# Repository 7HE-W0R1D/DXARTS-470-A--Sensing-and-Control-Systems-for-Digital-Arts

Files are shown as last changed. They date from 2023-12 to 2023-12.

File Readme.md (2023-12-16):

# RetroConnect: Retrofit Telephone 
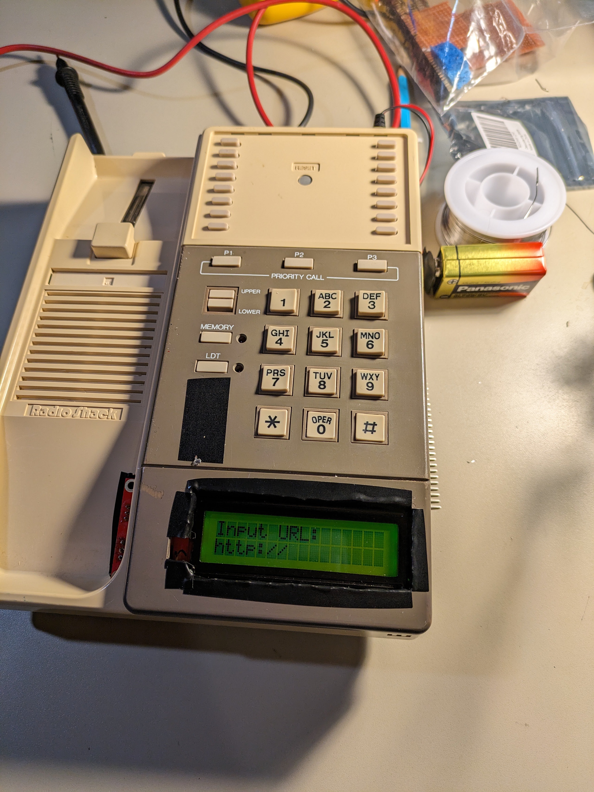
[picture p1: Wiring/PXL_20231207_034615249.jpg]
RetroConnect Phone


## Description
The Internet-Connected Retro Telephone is a project born out of a fascination with IoT and telecommunication. The motivation behind this endeavor is to explore the rapid evolution of technology and the stark differences in devices used over the past decades. By repurposing an old telephone, the project aims to showcase the transformative journey from traditional rotary dial phones to modern smart IoT devices. Additionally, it delves into the emergence of wireless technology, filling our surroundings with invisible data flows.

The project itself is a retrofit telephone equipped with up-to-date WiFi technology, serving as an interpreter of the invisible data flow around us. Users can connect to the internet using this device, experiencing the blend of old and new technologies. The telephone generates different characters and beeps at varying frequencies based on the delay of accessing websites. WiFi connectivity is provided through an ESP 8266 WiFi module connected to the Arduino, while character display is achieved using a 1602 Serial enabled LCD. Beeping and key input are facilitated through the telephone's original keypad and speaker.

## Table of Contents
- [Schematic](#schematic)
- [Installation](#installation)
- [Usage](#usage)

## Schematic
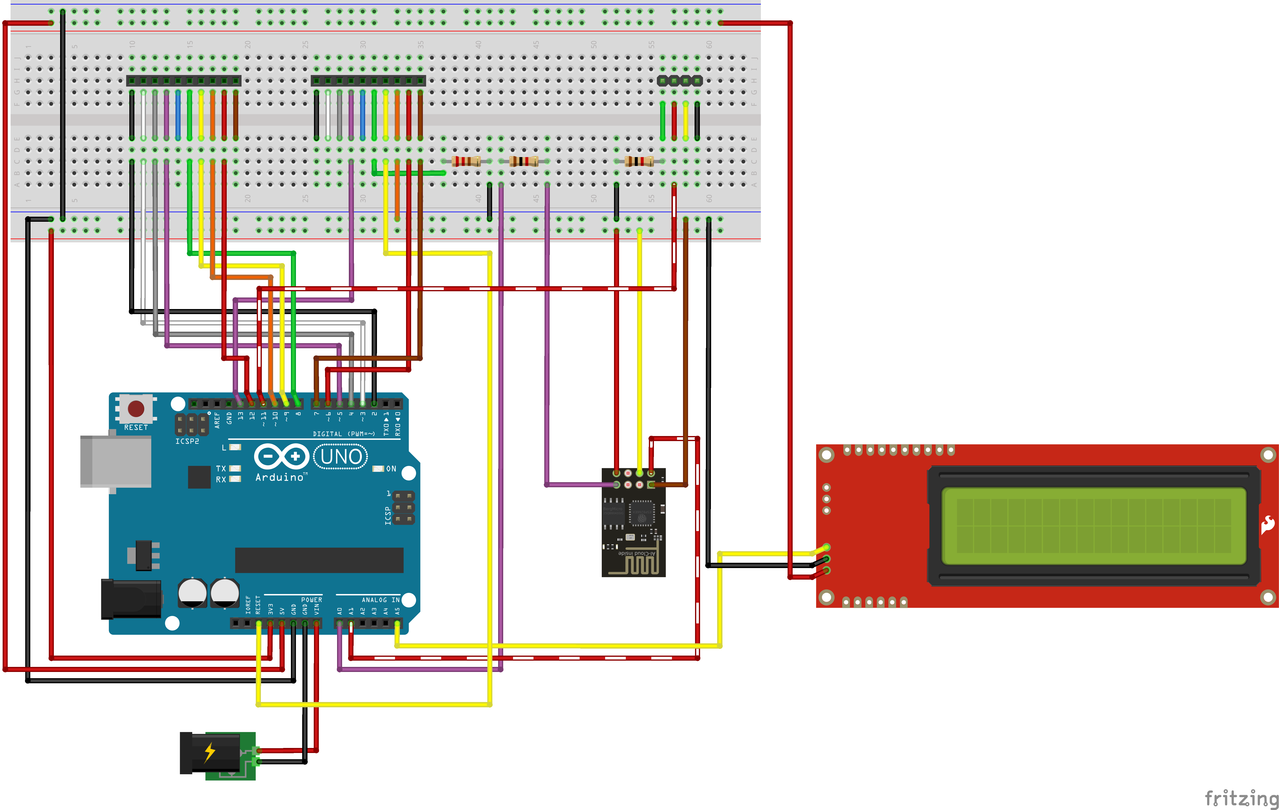
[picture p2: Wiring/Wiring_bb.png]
Wiring Breadboard View Wiring in Breadboard View

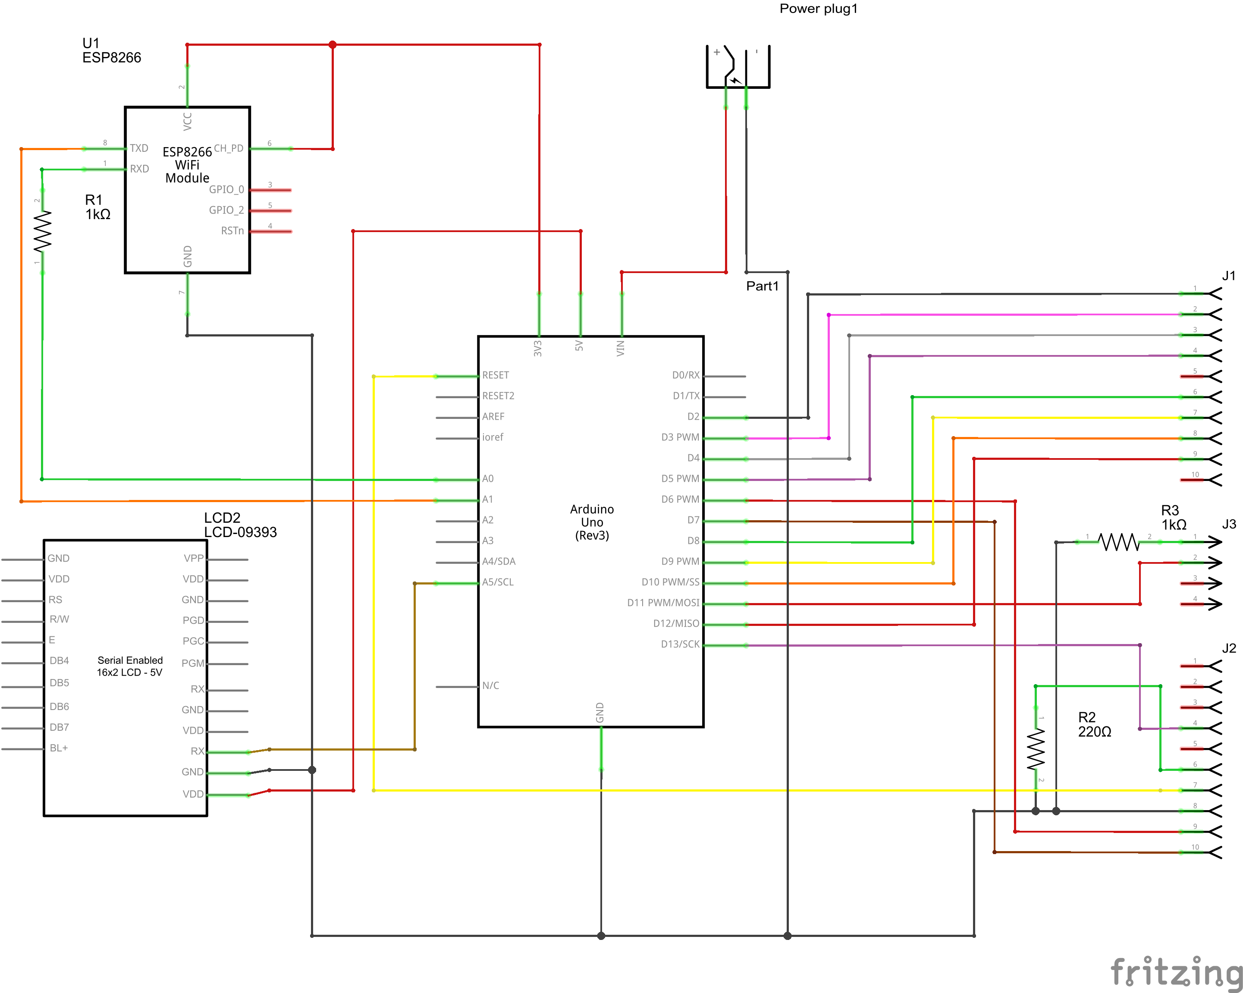
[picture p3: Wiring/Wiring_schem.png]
Wiring Schematic View Wiring in Shematic View

The two 10 pin connectors are the key connector from the telephone, the key mapping can be found in the __Phone Key test.xlsx__ file. Wires are in the same order in the breadboard graph and the actual connector, both from left to right. The 4 pin connector is the telephone's speaker & mic connector, also preserved the original color in the breadboard view. 
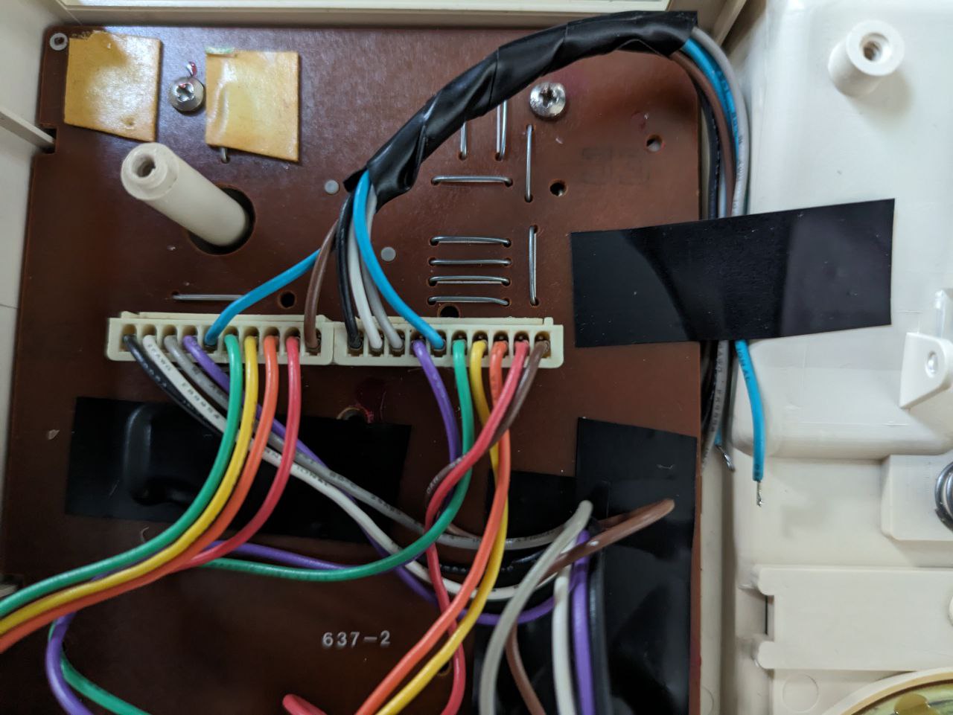
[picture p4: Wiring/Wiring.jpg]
Key Connector Key Connector Graph


## Installation Notes
Some important notes to make the phone work properly

- Connect the ESP 8266 WIFI module to the Arduino and run the ``ESP 8266 Setup.ino`` file once to set the default baud rate to 9600, 115200 is too fast for stable communication.
- When developing, do not send too many commands at once to the ESP 8266, add delays between commands
- The ``lcd.clear()`` function in the SerLCD library is not working properly so print spaces (" ") to clear the screen.
- Careful about the external reset button, especially when flipped the PCB board. Make sure the Arduino is not resetting infinitely.

## Usage
Once installed, RetroConnect can be used to connect to the internet and access websites. Users can input URLs using the original telephone keypad, and the device will respond with characters and beeps corresponding to the site's delay. This unique interaction aims to make users reflect on the evolution of technology while experiencing the charm of vintage communication devices.

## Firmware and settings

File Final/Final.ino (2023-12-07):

#include <SoftwareSerial.h>
#include <Keypad.h>
#include <Wire.h>
#include <SerLCD.h>

// LCD
SoftwareSerial lcdSerial(A4, A5); // RX, TX
SerLCD lcd;

// Wifi
SoftwareSerial espSerial(A1, A0); // RX, TX
String ssid_home = "BreakfastBerry";
String password_home = "N;9263k2";
String ssid_x13 = "ThinkPad";
String password_x13 = "AMD4750u";
String ssid = "UW MPSK";
// String password = ":$SpEL7<*7"; // Model 01 Old
String password = "EKAgE6=,Ur"; // Model 02 New

// Buzzer
int buzzerPin = 11; // set the buzzer pin
int frequency = 0; // initialize the frequency variable

static int Tones_simple[] ={31, 33, 37, 41, 44, 49, 55, 62, 65, 73, 82, 87, 98, 110, 123, 131, 147, 165,
 175, 196, 220, 247, 262, 294, 330, 349, 392, 440, 494, 523, 587, 659, 698, 784, 880, 988, 1047};

// Keypad
const byte ROWS = 4;
const byte COLS = 5;

// Wiring: 2 3 4 5 8 9 10 12 || 13

// < is P1, > is P2, ~ is P3
char keys[ROWS][COLS] = {
//          8    5    4    3    2
/* 9  */  {'~', '1', '2', '3', ' '},
/* 10 */  {'>', '4', '5', '6', '-'},
/* 13 */  {'<', '7', '8', '9', '_'},
/* 12 */  {'(', '*', '0', '#', '/'}
};

String multiEnabled = "0123456789";
String keyStringArray_Capital[10] = {
  "0Z.",
  "1", "2ABC", "3DEF",
  "4GHI", "5JKL", "6MNO",
  "7PQRS", "8TUV", "9WXY"
};

String keyStringArray[10] = {
  "0z.",
  "1", "2abc", "3def",
  "4ghi", "5jkl", "6mno",
  "7pqrs", "8tuv", "9wxy"
};

byte rowPins[ROWS] = {9, 10, 13, 12};
byte colPins[COLS] = {8, 5, 4, 3, 2};

Keypad keypad = Keypad(makeKeymap(keys), rowPins, colPins, ROWS, COLS);
int multiPressDelay = 1000;
String result = "";

// ASCII
String ASCIIStr = "";
char intToASCII(int , boolean = true);

String serialPrompt(String = "Please enter your PING target: ");

// LED
int ledUPin = 6; // Upper LED, PWM
int ledDPin = 7; // Lower LED, no PWM

void setup()
{
  pinMode(buzzerPin, OUTPUT); // set the buzzer pin as an output
  pinMode(ledUPin, OUTPUT);
  pinMode(ledDPin, OUTPUT);
  Serial.begin(9600);

  lcdSerial.begin(9600);
  // Initialize the LCD
  lcd.begin(lcdSerial);
  // Clear the LCD screen
  lcdClear();
  delay(500);

  espSerial.begin(9600);
  espSerial.listen();
  delay(500);
  digitalWrite(ledUPin, HIGH);
  delay(100);
  digitalWrite(ledDPin, HIGH);
  delay(500);
  digitalWrite(ledUPin, LOW);
  delay(100);
  digitalWrite(ledDPin, LOW);

  // Serial.println("Setting ESP8266 to station mode...");
  lcd.print("Setting ESP8266");
  lcd.setCursor(0, 1);
  lcd.print("to station mode...");
  espSerial.println("AT+CWMODE=1");
  delay(1000);

  lcdClear();
  // Serial.println("Connecting to WiFi...");
  lcd.print("WIFI Connecting");
  delay(50);
  // espSerial.println("AT+CWJAP_CUR=\"" + ssid_home + "\",\"" + password_home + "\"");
  // espSerial.println("AT+CWJAP_CUR=\"" + ssid_x13 + "\",\"" + password_x13 + "\"");
  espSerial.println("AT+CWJAP_CUR=\"" + ssid + "\",\"" + password + "\"");
  delay(4000);

  lcdClear();
  String response = readESPSerial();
  // Serial.println(response);

  if (response.indexOf("CONNECTED") != -1 || response.indexOf("GOT IP") != -1 || response.indexOf("OK") != -1
  || response.indexOf("WIFI CON") != -1)
  {
    // Serial.println("Connected to WiFi!");
    lcd.print("WIFI Connected");
    noTone(buzzerPin); // stop the tone
    tone(buzzerPin, Tones_simple[10]); // generate the tone with the specified frequency
    digitalWrite(ledUPin, HIGH);
    delay(50); // wait for 50 milliseconds
    noTone(buzzerPin); // stop the tone
    digitalWrite(ledUPin, LOW);
    delay(50); // wait for 50 milliseconds
    tone(buzzerPin, Tones_simple[10]); // generate the tone with the specified frequency
    digitalWrite(ledUPin, HIGH);
    delay(50); // wait for 50 milliseconds
    noTone(buzzerPin); // stop the tone
    digitalWrite(ledUPin, LOW);
  }
  else
  {
    // Serial.println("Failed to connect to WiFi! \nPlease reset the ESP8266 and try again.");
    // for (;;);
    lcd.print("WIFI Failed");
    tone(buzzerPin, Tones_simple[3]); // generate the tone with the specified frequency
    delay(500); // wait for 100 milliseconds
    noTone(buzzerPin); // stop the tone
  }

  delay(3000);

  lcdClear();
  // Serial.println("Getting IP Address");
  // lcd.print("Getting IP Addr");
  // espSerial.println("AT+CIPSTA_CUR?");
  // delay(2000);
  // String ipStr = readESPSerial();
  // // Serial.println(ipStr);
  // String ipAddr = ipStr.substring(ipStr.indexOf("\"") + 1, ipStr.lastIndexOf("\""));
  // ipAddr.replace("\r", "");
  // ipAddr.replace("\"", "");
  // // Serial.println("IP get: " + ipAddr + " END");
  // lcdClear();
  // lcd.print("IP Addr: ");
  // lcd.setCursor(0, 1);
  // lcd.print(ipAddr);
  randomSeed(analogRead(A2));
  // delay(3000);
}

void loop()
{
  lcdClear();
  // Serial.println("Welcome to the W3Phone!");
  lcd.print("Welcome to the ");
  lcd.setCursor(0, 1);
  lcd.print("W3Phone!");
  delay(3000);
  lcdClear();

  lcd.print("Surf the web");
  lcd.setCursor(0, 1);
  lcd.print("      w/ keypad!");
  delay(3000);
  lcdClear();

  ASCIIStr = "";
  String siteURL = readKeypadInput("Input URL: ");
  delay(1000);
  siteURL.toLowerCase();
  // Serial.println("Communicating with " + siteURL + ": ");
  lcdClear();
  lcd.print("Connecting to:");
  lcd.setCursor(0, 1);
  lcd.print("http://" + siteURL);
  delay(1000);
  lcdClear();
  lcd.print("Response:");
  lcd.setCursor(0, 1);
  for (int i = 0; i < 15; i++) {
    // Serial.println("pinging " + siteURL + ": ");
    int siteDelay = pingSite(siteURL);

    char ascii = intToASCII(siteDelay);
    ASCIIStr += ascii;
    // Serial.println("Response: " + ASCIIStr);
    // Serial.println(siteDelay);
    lcd.write(ascii);

    delay(50); // CANNOT DELETE THIS DELAY
    frequency = convertFreq(ConvNumber(siteDelay));
    // Serial.println(frequency);
    noTone(buzzerPin); // stop the tone
    tone(buzzerPin, frequency); // generate the tone with the specified frequency
    delay(250); // wait for 100 milliseconds

  }
  noTone(buzzerPin); // stop the tone
  delay(3000);
  lcdClear();
  lcd.print("Comm Complete");
  delay(1000);
  lcdClear();
  lcd.print("Thank you for");
  lcd.setCursor(0, 1);
  lcd.print("using W3Phone!");
  delay(3000);
}

String readESPSerial()
{
  String response = "";
  while (espSerial.available())
  {
    char c = espSerial.read();
    response += c;
  }
  return response;
}

int pingSite(String siteURL) {
  espSerial.println("AT+PING=\""+ siteURL +"\"");
  delay(1500);
  String response = readESPSerial();
  // Serial.println("response: " + response);

  if (response.indexOf("OK") != -1) {
    String siteDelay = response.substring(response.lastIndexOf("+") + 1, response.indexOf("OK") - 1);
    siteDelay.replace("\r", "");
    siteDelay.replace("\n", "");
    // Serial.println("Ping delay: " + siteDelay + "ms");
    
    return siteDelay.toInt();
  } else {
    return -1;
  }
}

String serialPrompt(String prompt = "Please enter your PING target: ") {
  Serial.println(prompt);

  while(Serial.available() == 0){
  }

  String input = Serial.readString();
  return input;
}

String readKeypadInput(String prompt)
{
  String result = "";
  String displayString = "";
  String prefix = "http://";
  // Serial.println(prompt);

  lcd.print(prompt);
  lcd.setCursor(0, 1);
  lcd.print(prefix);
  for (;;)
  {
    static unsigned long lastMillis = 0;
    static char lastKey = NO_KEY;
    static int keyCount = 0;
    char key = keypad.getKey();

    if (key != NO_KEY)
    {
      // Beep when key is pressed
      int keyStringIndex = multiEnabled.indexOf(key);
      int frequency = Tones_simple[keyStringIndex * 3 + 10];
      tone(buzzerPin, frequency); // generate the tone with the specified frequency
      digitalWrite(ledUPin, HIGH);
      delay(30);
      noTone(buzzerPin); // stop the tone
      digitalWrite(ledUPin, LOW);

      // Special keys first
      if (key == '#')
      {
        // Serial.println("Final result: " + result);
        displayString = prefix + result;
        displayString = displayString.substring(0, 16);
        lcdClear();
        lcd.print("Entered:");
        lcd.setCursor(0, 1);
        lcd.print(displayString);
        return result;
      }

      if (key == '*')
      {
        result = result.substring(0, result.length() - 1);
        // Serial.println("Result: " + result);
        displayString = prefix + result;
        displayString = displayString.substring(0, 16);
        lcdClear();
        lcd.print(prompt);
        lcd.setCursor(0, 1);
        lcd.print(displayString);
        continue;
      }

      if (key == '~')
      {
        result = "webfoundation.org";
        displayString = prefix + result;
        if (displayString.length() > 16) {
          displayString = displayString.substring(displayString.length() - 16, displayString.length());
        }
        lcdClear();
        lcd.print(prompt);
        lcd.setCursor(0, 1);
        lcd.print(displayString);
        return result;
      }

      if (key == '>') {
        result = "bing.com";
        displayString = prefix + result;
        if (displayString.length() > 16) {
          displayString = displayString.substring(displayString.length() - 16, displayString.length());
        }
        lcdClear();
        lcd.print(prompt);
        lcd.setCursor(0, 1);
        lcd.print(displayString);
        return result;
      }

      if (key == '<') {
        result = "8.8.8.8";
        displayString = prefix + result;
        if (displayString.length() > 16) {
          displayString = displayString.substring(displayString.length() - 16, displayString.length());
        }
        lcdClear();
        lcd.print(prompt);
        lcd.setCursor(0, 1);
        lcd.print(displayString);
        return result;
      }

      // Multi key press key detection
      if (multiEnabled.indexOf(key) >= 0 && key == lastKey && millis() - lastMillis < multiPressDelay)
      {
        // Serial.print("Multi key press: ");

        char finalKey;
        int keyStringIndex = multiEnabled.indexOf(key);
        String keyString = keyStringArray[keyStringIndex];
        finalKey = keyString[keyCount % keyString.length()];
        // Serial.println(finalKey);
        result = result.substring(0, result.length() - 1) + finalKey;
        lastMillis = millis();
        keyCount++;
      }
      else
      {
        lastKey = key;
        lastMillis = millis();
        keyCount = 1;
        result += key;

      }

      // Serial.println("Result: " + result);
      displayString = prefix + result;
      if (displayString.length() > 16) {
        displayString = displayString.substring(displayString.length() - 16, displayString.length());
      }
      lcdClear();
      lcd.print(prompt);
      lcd.setCursor(0, 1);
      lcd.print(displayString);
    }
  }
}

char intToASCII(int num, boolean charOnly = true)
{
  int mapped = 0;
  if (charOnly)
  {

    if (num <= 0)
    {
      return ' ';
    }

    mapped = (abs(num) % 64) + 64;

    if ((mapped >= 91 && mapped <= 96) ||
       (mapped >= 123 && mapped <= 126) ||
       (mapped == 0))
    {
      return ' ';
    }
  }
  else {
    mapped = abs(num) % 128;
  }

  // Serial.println(mapped);
  char result = mapped;
  return result;
}

int convertFreq(int inputFreq){
  int frequency = inputFreq;
  // int digit2 = inputFreq % 10 + 1;
  // frequency = (inputFreq * digit2);
  frequency = 1047 * (sin(1.618 * (frequency - (PI / 2))) + 1) / 2;
  // Serial.print(frequency);
  // Serial.print(" ");
  int toneFreq = matchTone(frequency) * 0.618;
  // Serial.println(toneFreq);
  return toneFreq;
}

int matchTone(int inputTone) {
  for (int i = 0; i < sizeof(Tones_simple) - 1; i++) {
    if (inputTone <= (Tones_simple[i] + Tones_simple[i + 1]) / 2) {
      return Tones_simple[i];
    }
  }
  return Tones_simple[sizeof(Tones_simple) - 1];
}

int prevNumber = -1;
int prevResult = -1;
int ConvNumber (int Input) {
    if (prevNumber == Input) {
        return prevResult;
    } else {
        prevNumber = Input;
        prevResult = ConvNumber_Map(Input);
        return prevResult;
    }
}

int ConvNumber_Map(int Input) {
    const int RANGE = 6;
    int randNumber = random(RANGE);
    return Input + randNumber - (RANGE - 1) / 2;
}

void reset() {
  Serial.println("reset");
  espSerial.println("AT+RST");
  delay(1000);
  if(espSerial.find("OK") ) Serial.println("Module Reset");
}

void lcdClear() {
  lcd.setCursor(0, 0);
  lcd.print("                ");
  lcd.setCursor(0, 1);
  lcd.print("                ");
  lcd.setCursor(0, 0);
}

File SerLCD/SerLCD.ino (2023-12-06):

#include <Wire.h>
#include <SerLCD.h>
#include <SoftwareSerial.h>

SoftwareSerial espSerial(A1, A0); // RX, TX
SoftwareSerial lcdSerial(A4, A5); // RX, TX

// Create an instance of the SerLCD class
SerLCD lcd;

void setup() {
  Serial.begin(9600);
  lcdSerial.begin(9600);
  // Initialize the LCD
  lcd.begin(lcdSerial);
  delay(500);
  // Clear the LCD screen

  espSerial.begin(9600);
  espSerial.listen();
  
  delay(500);
  lcd.print("Hello, World!");
  // Serial.println("Serial!");
  lcd.print("Wow");
}

void loop() {
  lcdClear();
  lcd.print("Hello, World!");
  lcd.setCursor(0, 1);
  lcd.print(millis() / 1000);
  delay(500);
  // Set the cursor to column 0, line 1
  // (note: line 1 is the second row, since counting begins with 0):
  // lcd.setCursor(0, 1);
  // Print the number of seconds since reset:

}

void lcdClear() {
  lcd.setCursor(0, 0);
  lcd.print("                ");
  lcd.setCursor(0, 1);
  lcd.print("                ");
  lcd.setCursor(0, 0);
}

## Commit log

2023-11-17 [ improve ] Buzzer tone improve
    [Buzzer.ino, Final.ino]
2023-12-03 [ add ] Add basic LED output
2023-12-16 [ add ] Add readme and supporting files
    [Phone Key Test.xlsx, Wiring.fzz]
